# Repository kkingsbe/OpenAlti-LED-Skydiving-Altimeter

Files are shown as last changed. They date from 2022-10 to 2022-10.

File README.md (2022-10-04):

# OpenAlti-LED-Skydiving-Altimeter
This is an open-source version of the ColorAlti skydiving altimeter. This device features a barometric pressure sensing altimeter for determining altitude, 
and 3 2020-sized neopixels for relaying altitude information to the skydiver. This project is still early in its design phase, so this readme will be fleshed
out with much more information including build instructions eventually. This product will never be for sale, but the plans & firmware will always be free.

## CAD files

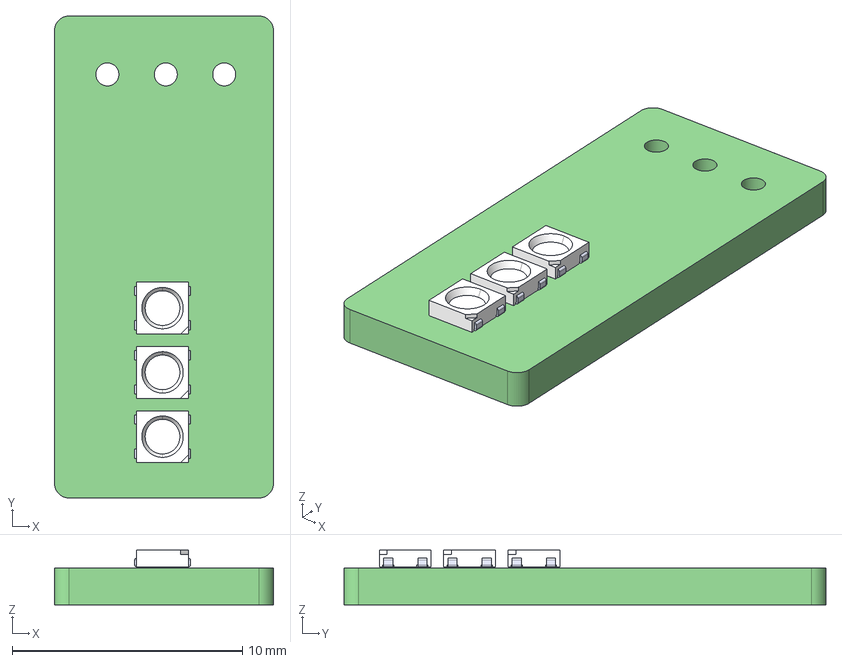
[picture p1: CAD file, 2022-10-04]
PCBS/Neopixel Board/Neopixel Board.step
9.53 x 21.0 x 2.38 mm
Neopixel Board PCB

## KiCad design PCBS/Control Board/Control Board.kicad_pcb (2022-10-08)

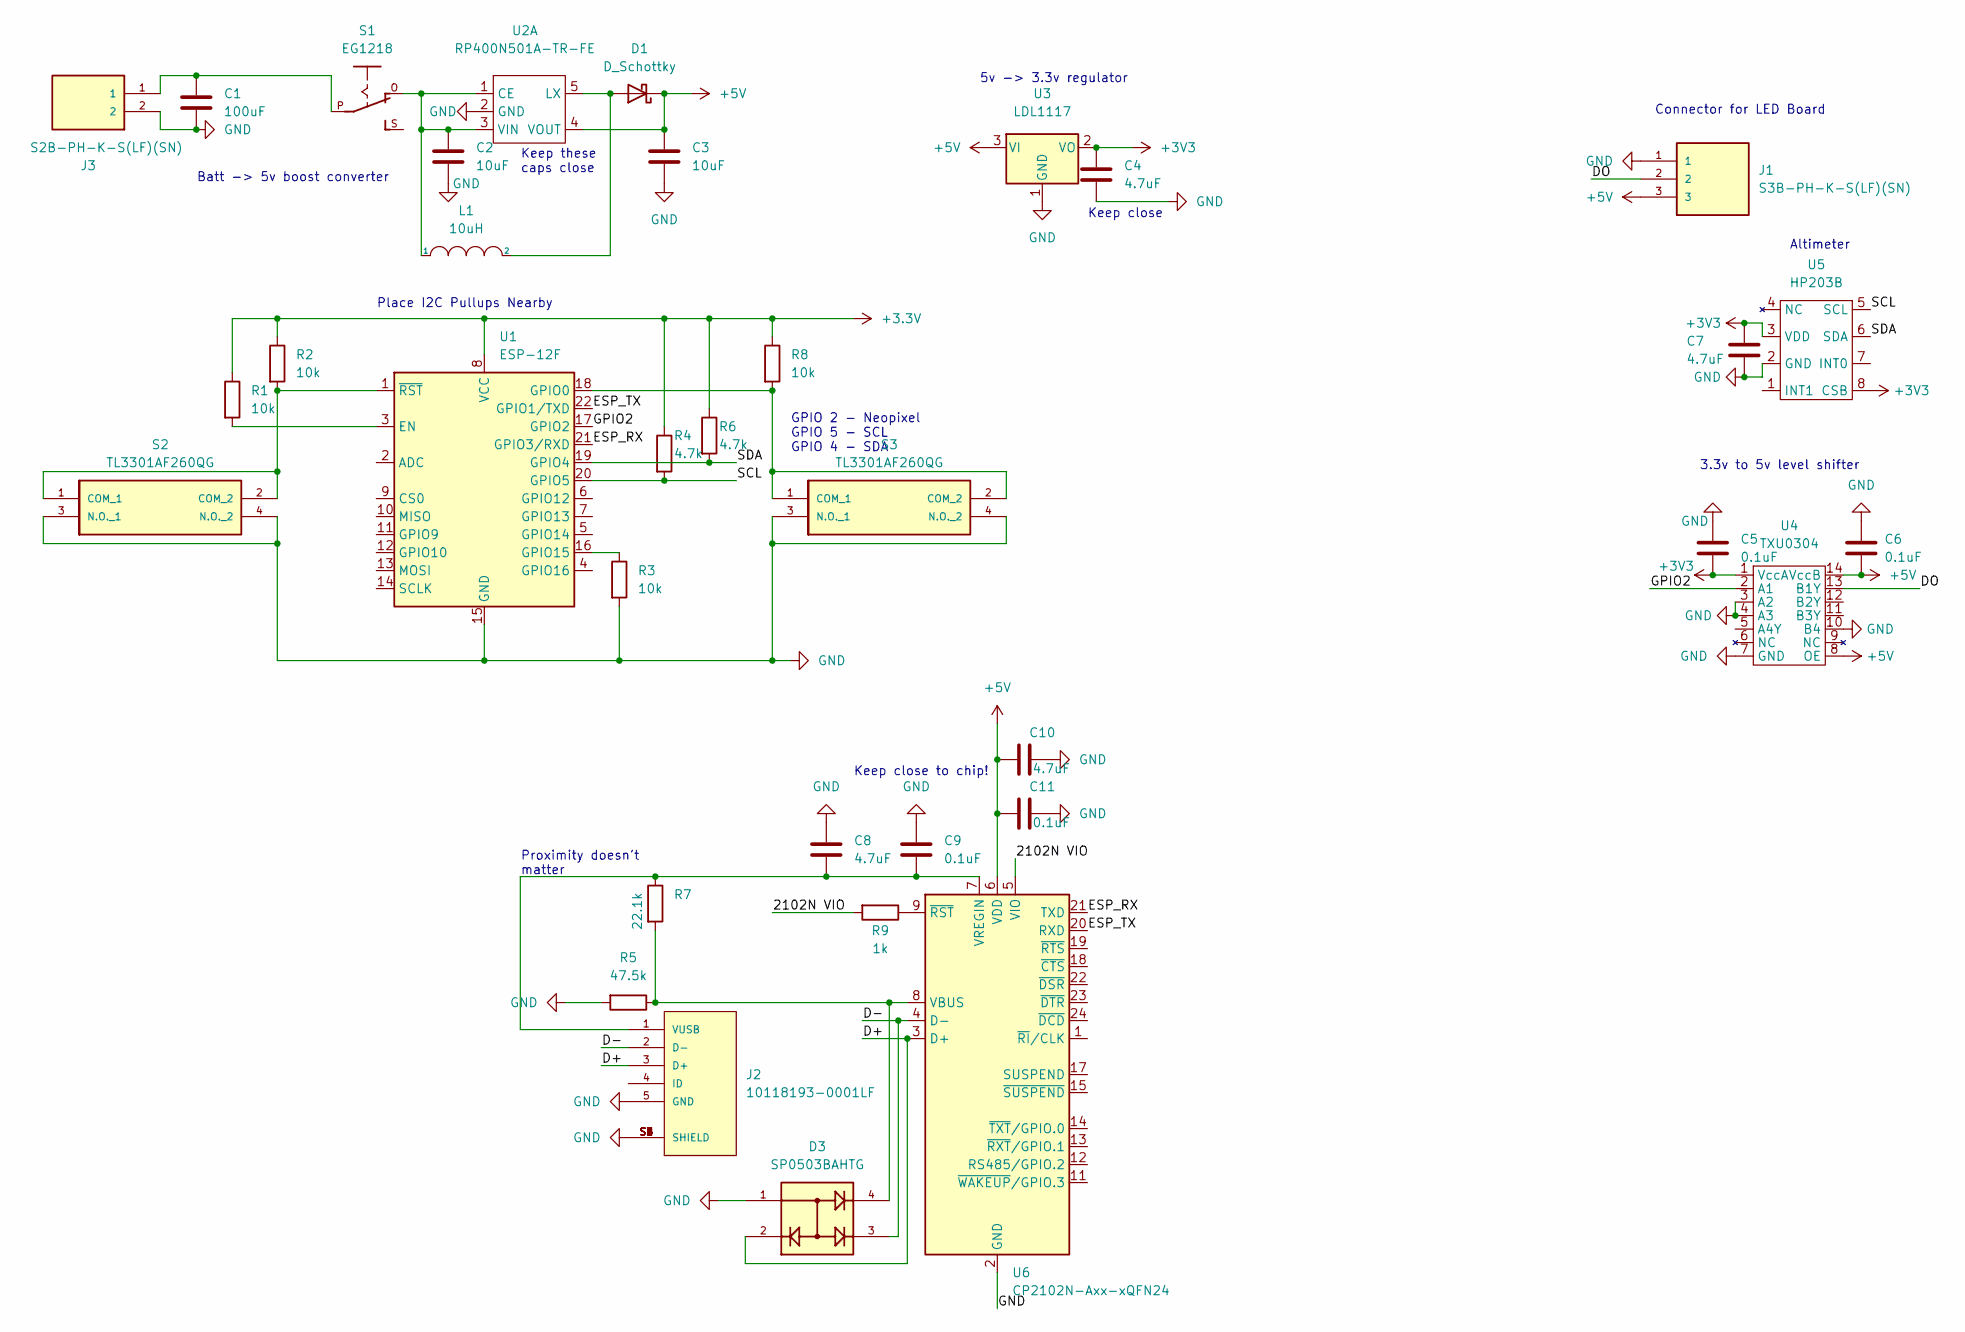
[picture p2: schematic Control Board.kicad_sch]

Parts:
C1: 100uF; C_1206_3216Metric
C2, C3: 10uF; C_0805_2012Metric
C4: 4.7uF; C_0805_2012Metric
C5, C6: 0.1uF; C_0402_1005Metric
C7: 4.7uF; C_0402_1005Metric
C8, C10: 4.7uF; C_0402_1005Metric; LCSC C129235
C9, C11: 0.1uF; C_0402_1005Metric; LCSC C325696
D1: D_Schottky; D_SOD-123
D3: SP0503BAHTG; SOT143; PARTREV N/A; LCSC C7074
J1: S3B-PH-K-S(LF)(SN); JST_S3B-PH-K-S(LF)(SN)
J2: 10118193-0001LF; FCI_10118193-0001LF
J3: S2B-PH-K-S(LF)(SN); JST_S2B-PH-K-S(LF)(SN)
L1: 10uH; IND_SLF7045T-100M1R3-PF
R1, R2, R3, R8: 10k; R_0402_1005Metric; LCSC C17414
R4, R6: 4.7k; R_0402_1005Metric; LCSC C17673
R5: 47.5k; R_0402_1005Metric; LCSC C23061
R7: 22.1k; R_0402_1005Metric; LCSC C325588
R9: 1k; R_0603_1608Metric; LCSC C21190
S1: EG1218
S2, S3: TL3301AF260QG; MANUFACTURER_PART_NUMBER TL3301AF260QG; MOUSER_PART_NUMBER 612-TL3301AF2
U1: ESP-12F; ESP-12E; LCSC C82891
U2: RP400N501A-TR-FE; SOT-23-5
U3: LDL1117; SOT-223-3_TabPin2
U4: TXU0304; TSSOP-14_4.4x5mm_P0.65mm
U5: HP203B
U6: CP2102N-Axx-xQFN24; QFN-24-1EP_4x4mm_P0.5mm_EP2.6x2.6mm; LCSC C969151

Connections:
+5V: C3.1, C6.2, C10.2, C11.2, D1.1 (K), J1.3, U2.4 (VOUT), U3.3 (VI), U4.8 (OE), U4.14 (VccB), U6.6 (VDD)
/2102N VIO: R9.2, U6.5 (VIO)
/D+: D3.2, J2.3 (D+), U6.3 (D+)
/D-: D3.3, J2.2 (D-), U6.4 (D-)
/DO: J1.2, U4.13 (B1Y)
/ESP_RX: U1.21 (GPIO3/RXD), U6.21 (TXD)
/ESP_TX: U1.22 (GPIO1/TXD), U6.20 (RXD)
/GPIO2: U1.17 (GPIO2), U4.2 (A1)
/SCL: R4.2, U1.20 (GPIO5), U5.5 (SCL)
/SDA: R6.2, U1.19 (GPIO4), U5.6 (SDA)
GND: C1.2, C2.2, C3.2, C4.2, C5.1, C6.1, C7.2, C8.1, C9.1, C10.1, C11.1, D3.1, J1.1, J2.5 (GND), J2.S1 (SHIELD), J2.S2 (SHIELD), J2.S3 (SHIELD), J2.S4 (SHIELD), J2.S5 (SHIELD), J2.S6 (SHIELD), J3.2, R3.2, R5.2, S2.3 (N.O._1), S2.4 (N.O._2), S3.3 (N.O._1), S3.4 (N.O._2), U1.15 (GND), U2.2 (GND), U3.1 (GND), U4.3 (A2), U4.4 (A3), U4.7 (GND), U4.10 (B4), U5.2 (GND), U6.2 (GND), U6.25 (GND)
unnamed: C1.1, J3.1, S1.P
unnamed: C2.1, L1.1, S1.O, U2.1 (CE), U2.3 (VIN)
unnamed: C8.2, C9.2, J2.1 (VUSB), R7.1, U6.7 (VREGIN)
unnamed: D1.2 (A), L1.2, U2.5 (LX)
unnamed: D3.4, R5.1, R7.2, U6.8 (VBUS)
unnamed: R1.2, U1.3 (EN)
unnamed: R2.2, S2.1 (COM_1), S2.2 (COM_2), U1.1 (~RST)
unnamed: R3.1, U1.16 (GPIO15)
unnamed: R8.2, S3.1 (COM_1), S3.2 (COM_2), U1.18 (GPIO0)
unnamed: R9.1, U6.9 (~RST)

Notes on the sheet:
Keep these caps close
Batt -> 5v boost converter
Keep close to chip!
Proximity doesn't matter
Keep close
Place I2C Pullups Nearby
Altimeter
3.3v to 5v level shifter
5v -> 3.3v regulator
GPIO 2 - Neopixel GPIO 5 - SCL GPIO 4 - SDA
Connector for LED Board

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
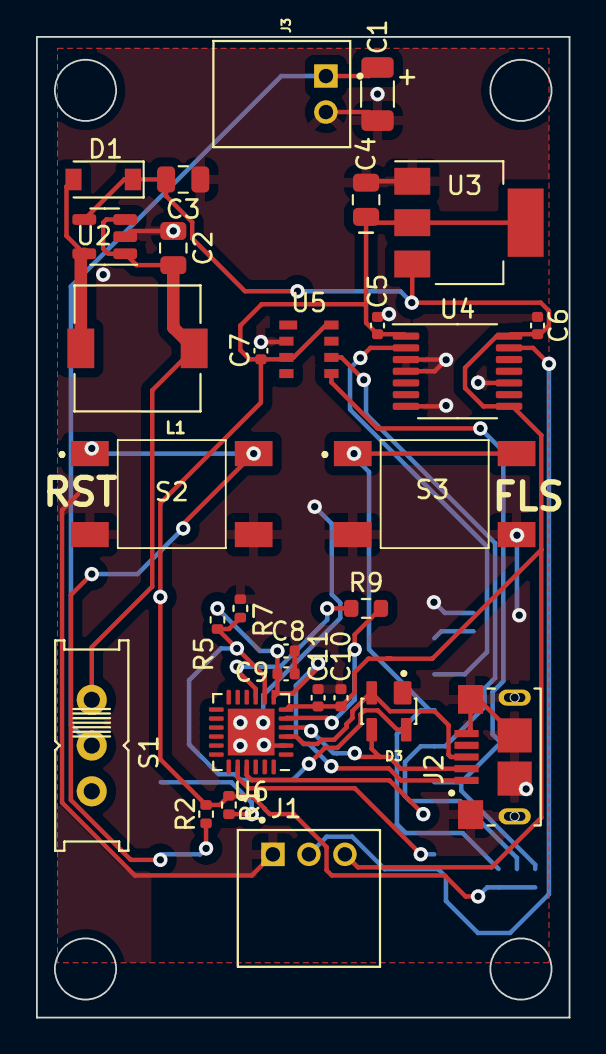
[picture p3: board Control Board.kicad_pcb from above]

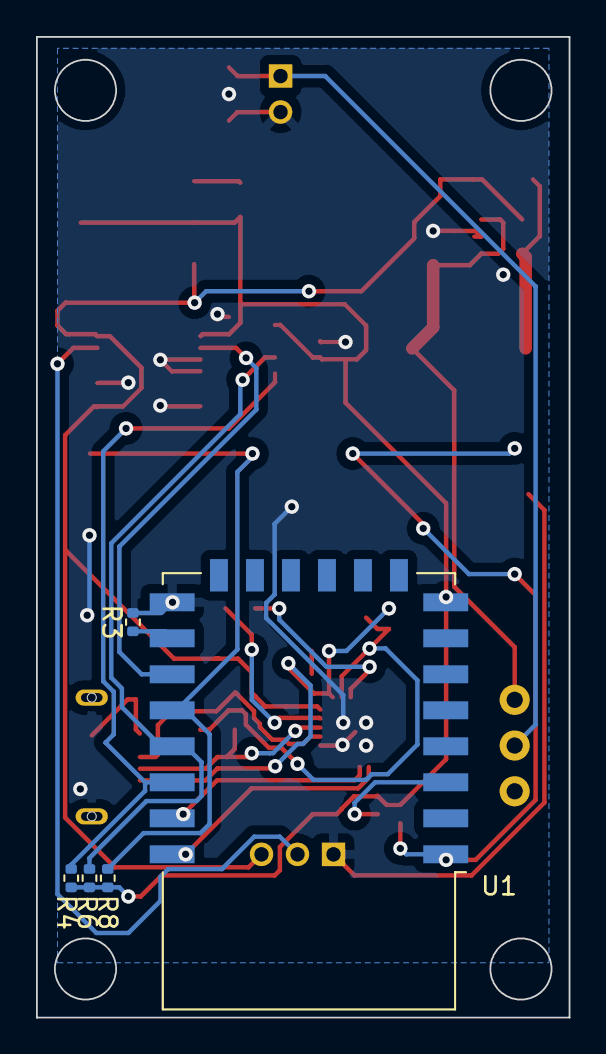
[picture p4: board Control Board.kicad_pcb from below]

Board: 2 copper layers, 29.6 x 54.5 mm, 35 parts (5 on the bottom side), 22 nets.

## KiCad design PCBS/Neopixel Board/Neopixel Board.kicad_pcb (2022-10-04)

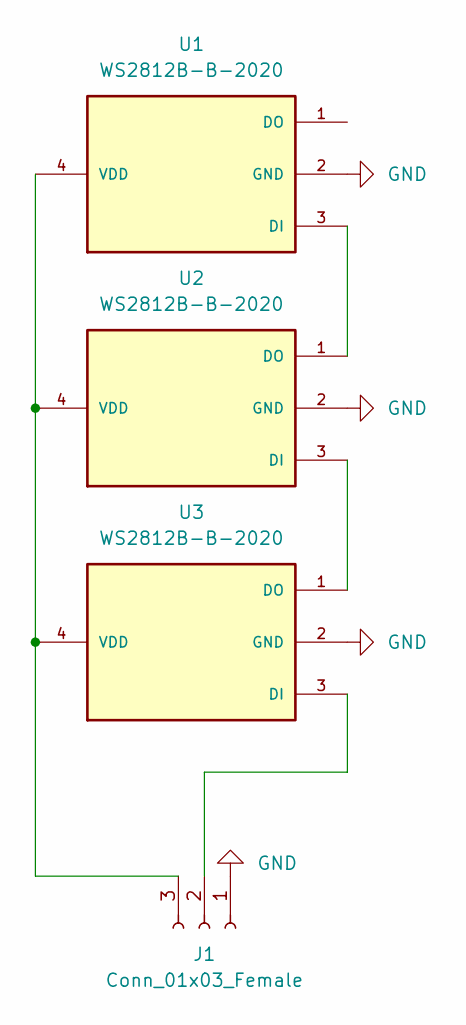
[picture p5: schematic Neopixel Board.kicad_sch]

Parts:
J1: Conn_01x03_Female; PinHeader_1x03_P2.54mm_Vertical
U1, U2, U3: WS2812B-B-2020; LED_WS2812B-2020; PARTREV 5

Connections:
GND: J1.1, U1.2 (GND), U2.2 (GND), U3.2 (GND)
unnamed: J1.2, U3.3 (DI)
unnamed: J1.3, U1.4 (VDD), U2.4 (VDD), U3.4 (VDD)
unnamed: U1.3 (DI), U2.1 (DO)
unnamed: U2.3 (DI), U3.1 (DO)

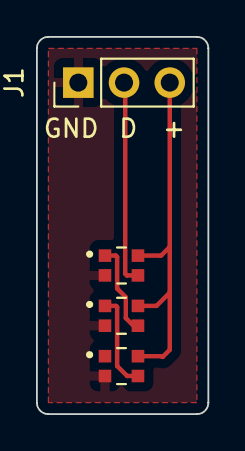
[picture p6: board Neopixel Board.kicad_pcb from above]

Board: 2 copper layers, 9.5 x 21.0 mm, 4 parts (0 on the bottom side), 5 nets.

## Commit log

2022-10-04 Updated schematic, started updating layout
    [Control Board.kicad_pcb, Control Board.kicad_sch]
2022-10-08 Completed switch to ESP-12F
    [Control Board.kicad_pcb]
